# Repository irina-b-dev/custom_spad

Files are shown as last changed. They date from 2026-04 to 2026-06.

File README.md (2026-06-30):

# Custom Single Photon Avalanche Detection system with integrated coincidence logic

## Overview
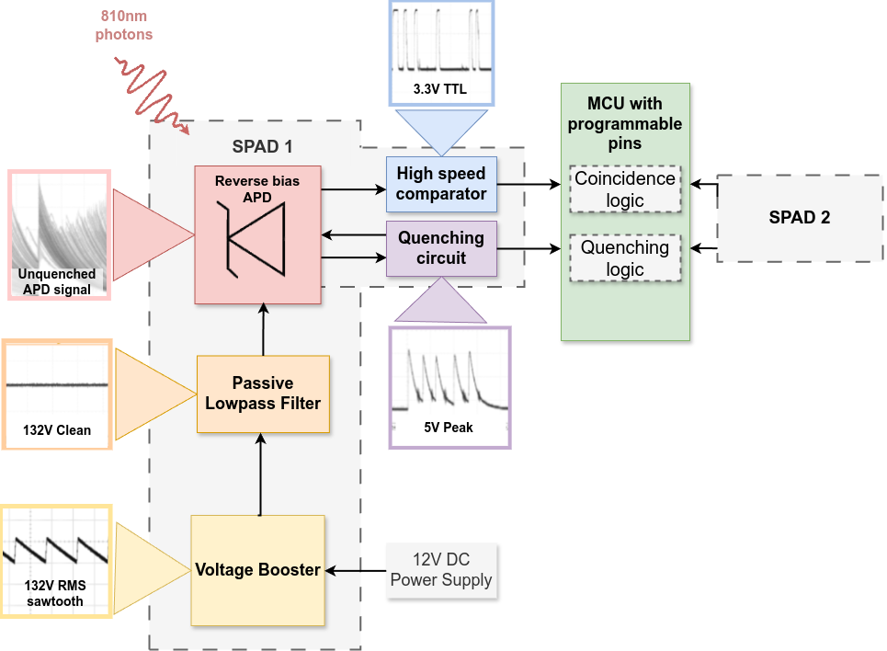
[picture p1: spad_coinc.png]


## BOM

Minimal working

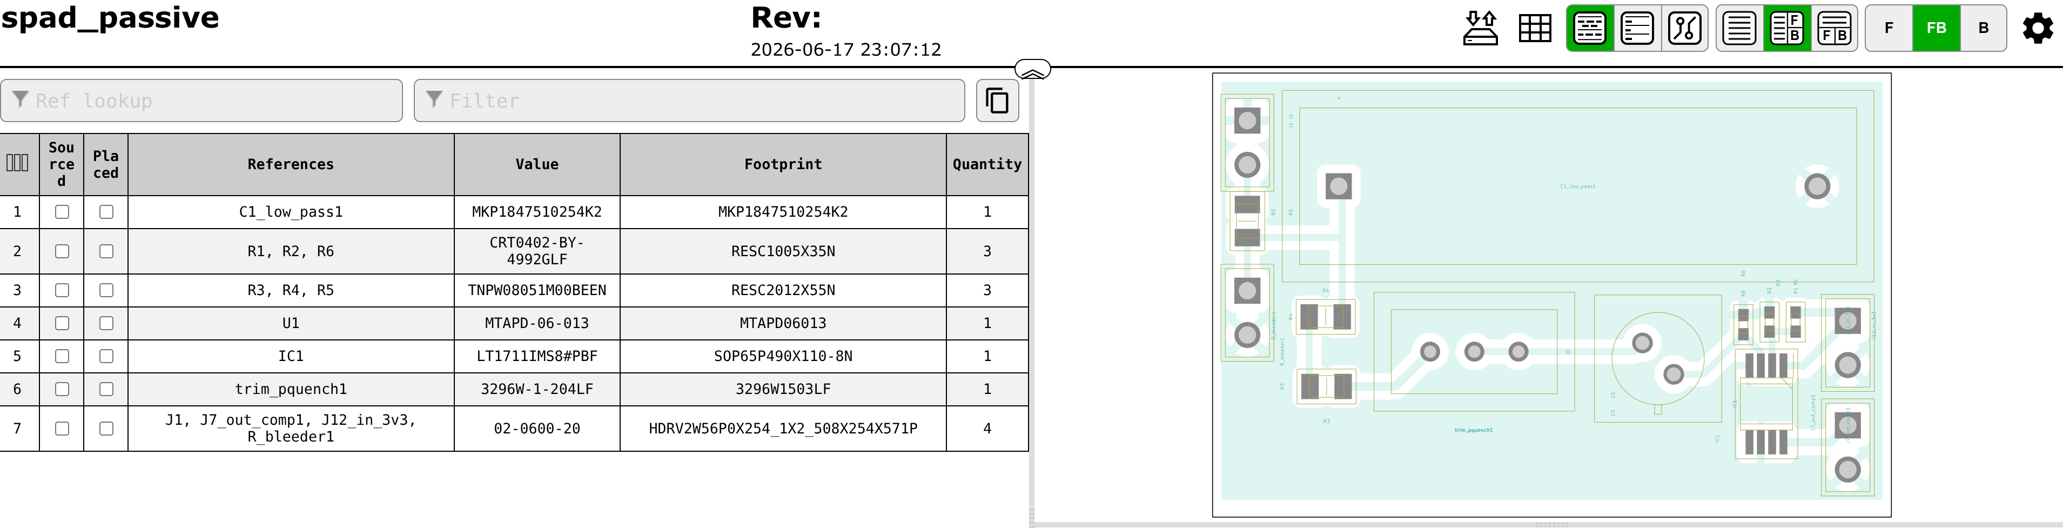
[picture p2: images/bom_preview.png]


[bom_interactive](./bom/ibom.html)

## BOM in test

### APD
| Name | Link | Price | Qty | Description | Code | Check |
| ---- | --- | --- | --- | --- | --- | ----- |
| APD  | https://ro.mouser.com/ProductDetail/193-MTAPD-06-001 | 37,21 € | 2 | Peak Wavelength: 800nm | 193-MTAPD-06-001 | [x] |

### Voltage Booster + Filter

| | | | | | | | | |
| --- | --- | --- | --- | ----- | --- | ---- | --- | --- |
| ---  --- |
| Ref. | Mfg. | Part No.  | Description |
| R | -- | -- | resistor | 100K  | | | | |
| C3 | -- | -- | capacitor | 1µF | | | | |
|YH11068A | | | | booster | |

### Quenching + Comparator

| | | | | | | | | |
| --- | --- | --- | --- | ----- | --- | ---- | --- | --- |
| ---  --- | | For SPAD  | | | | | | |
| | | | | | | | | |
| Ref. | Mfg. | Part No.  | Description | | | | | |
| APD | -- | DAPD | diode | | | | | |
| C1 | -- | -- | capacitor | 33µF  | 2.7V | | | |
| C2 | -- | -- | capacitor | 1µF | | | | |
| C3 | -- | -- | capacitor | 1µF | | | | |
| C4 | -- | -- | capacitor | 1µF | | | | |
| C5 | -- | -- | capacitor | 100nF | | | | |
| C6 | -- | -- | capacitor | 10nF  | | | | |
| C7 | -- | -- | capacitor | 100nF | | | | |
| C8 | -- | -- | capacitor | 100nF | | | | |
| Cj | -- | -- | capacitor | 1pF | 1KV | | | |
| Cn | -- | -- | capacitor | 10nF  | | | | |
| D1 | OnSemi | 1N5818 | diode | | | | | |
| D2 | OnSemi | 1N5819 | diode | | | | | |
| D3 | Vishay | BAT54 | diode | | | | | |
| D4 | Rohm | BAS21HY | diode | | | | | |
| D5 | Rohm | BAS21HY | diode | | | | | |
| L1 | -- | -- | inductor | 33µH  | 1.35A pk | | | |
| M1 | International Rectifier | IRF7832 | MOSFET | | | | | |
| M2 | Siliconix | Si7336ADP | MOSFET | | | | | |
| maboi | -- | -- | resistor | 1M | | | | |
| R1 | -- | -- | resistor | 1M | 1.00% | 0.1W | | |
| R2 | -- | -- | resistor | 100K  | | | | |
| R3 | -- | -- | resistor | 49.9K | | | | |
| R4 | -- | -- | resistor | 6.8K  | | | | |
| R5 | -- | -- | resistor | 20K | | | | |
| R6 | -- | -- | resistor | 300 | | | | |
| R7 | -- | -- | resistor | 1K | | | | |
| R8 | -- | -- | resistor | 1.9K  | | | | |
| R9 | -- | -- | resistor | 6K | | | | |
| R10 | -- | -- | resistor | 500K  | | | | |
| R11 | -- | -- | resistor | 1K | | | | |
| R13 | -- | -- | resistor | 150K  | | | | |
| Rbias | -- | -- | resistor | 14K | | | | |
| Rbias1 | -- | -- | resistor | 10K | | | | |
| Rdivider | -- | -- | resistor | 140K  | | | | |
| Rdrain | -- | -- | resistor | 90K | | | | |
| Re0 | -- | -- | resistor | 10 | | | | |
| Ri | -- | -- | resistor | 200K  | | | | |
| Rth | -- | -- | resistor | 1M | | | | |
| U1 | Analog Devices | LT1172 | integrated circuit | | | | | |
| U2 | Analog Devices | LT1711 | integrated circuit | | | | | |
| U3 | Analog Devices | AD8605 | integrated circuit | | | | | |
| | | | | | | | | |
| RP_Pico | | Rasberry Pi Pico |  MCU | | | | | |
| | | | | | | | | |

## PIO snippet for detection

```asm

.program detect_pulse

; Assumes:
; - Pin 2 - 4,5 = pulse input
; - Pin  0 - 2,3 = gate/control pin
; - pin base in C must include both

start:
    wait 1 pin 2           ; Wait for rising edge on pulse input
    ;wait 1 pin 0
    jmp pin do_push                       ;jmp pin do_push     ; 
    jmp do_push     ;jmp start              ; Otherwise, skip

do_push:
    in x, 32               ; 
    push block
    jmp start
```

### Note
This project is part of a [bigger project](https://github.com/irina-b-dev/custom-qkd-source)

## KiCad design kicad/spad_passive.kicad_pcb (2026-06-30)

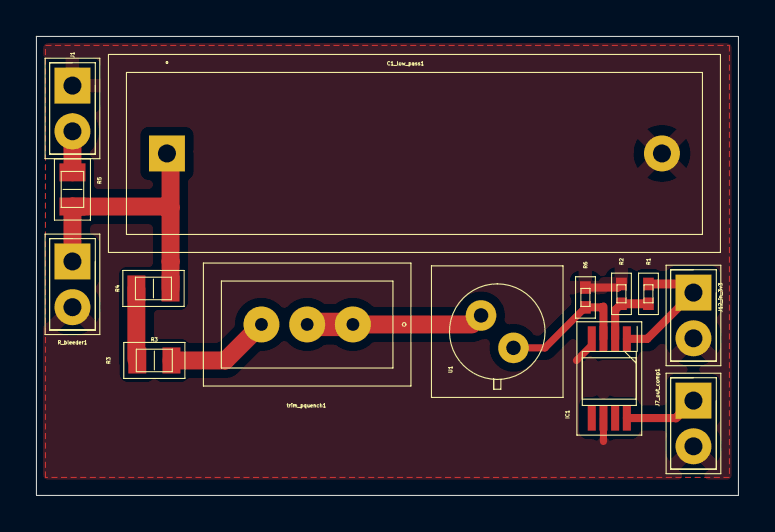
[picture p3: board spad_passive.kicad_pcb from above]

Board: 2 copper layers, 39.0 x 25.5 mm, 14 parts (0 on the bottom side), 10 nets.

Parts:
C1_low_pass1: MKP1847510254K2
IC1: LT1711IMS8#PBF; SOP65P490X110-8N
J1, J7_out_comp1, J12_in_3v3: 02-0600-20; HDRV2W56P0X254_1X2_508X254X571P
R1, R2, R6: CRT0402-BY-4992GLF; RESC1005X35N
R3, R4, R5: TNPW08051M00BEEN; RESC2012X55N
R_bleeder1: 02-0600-20; HDRV2W56P0X254_1X2_508X254X571P
U1: MTAPD-06-013; MTAPD06013
trim_pquench1: 3296W-1-204LF; 3296W1503LF

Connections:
+3.3V: IC1.1 (V+), J12_in_3v3.1, R1.2
+132V: J1.2, R5.1
GND: C1_low_pass1.2, IC1.4 (V-), IC1.6 (GND), J1.1, J7_out_comp1.2, J12_in_3v3.2, R2.2, R6.2, R_bleeder1.2
unnamed: C1_low_pass1.1, R4.1, R5.2, R_bleeder1.1
unnamed: IC1.2 (+IN), R1.1, R2.1
unnamed: IC1.3 (-IN), R6.1, U1.2 (APD+)
unnamed: IC1.8 (~Q), J7_out_comp1.1
unnamed: R3.1, R4.2
unnamed: R3.2, trim_pquench1.3
unnamed: U1.1 (APD-), trim_pquench1.1, trim_pquench1.2

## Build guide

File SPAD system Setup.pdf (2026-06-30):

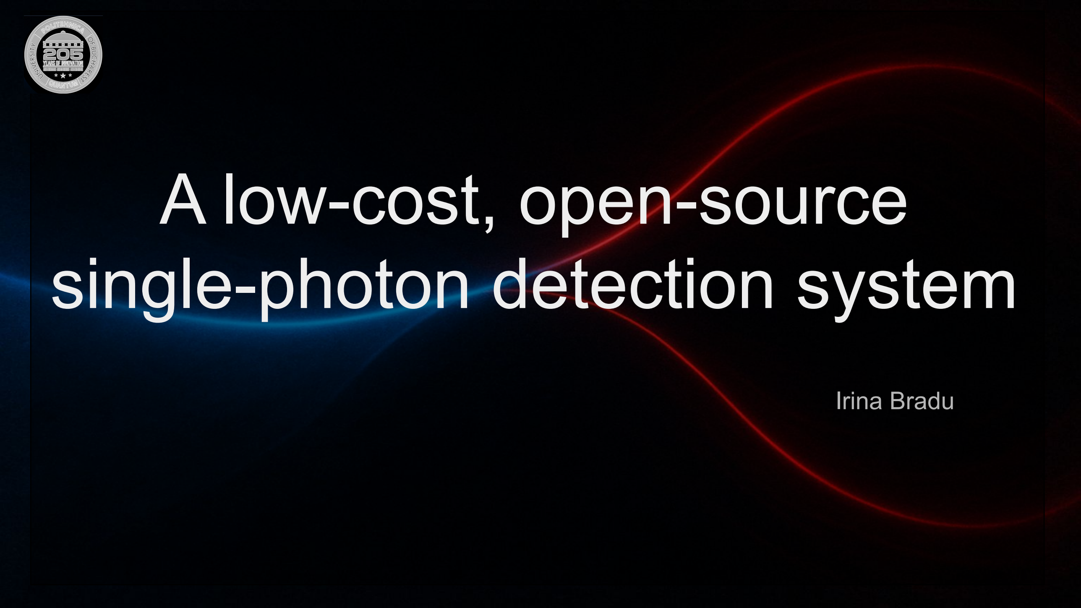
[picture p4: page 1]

# A low-cost, open-source single-photon detection system

Irina Bradu

Motivation

- Educational outreach
- Hardware experimentation
- Cost constraints

This was made at home.

This project was fully self founded.

Open-source, so you can try it yourself.

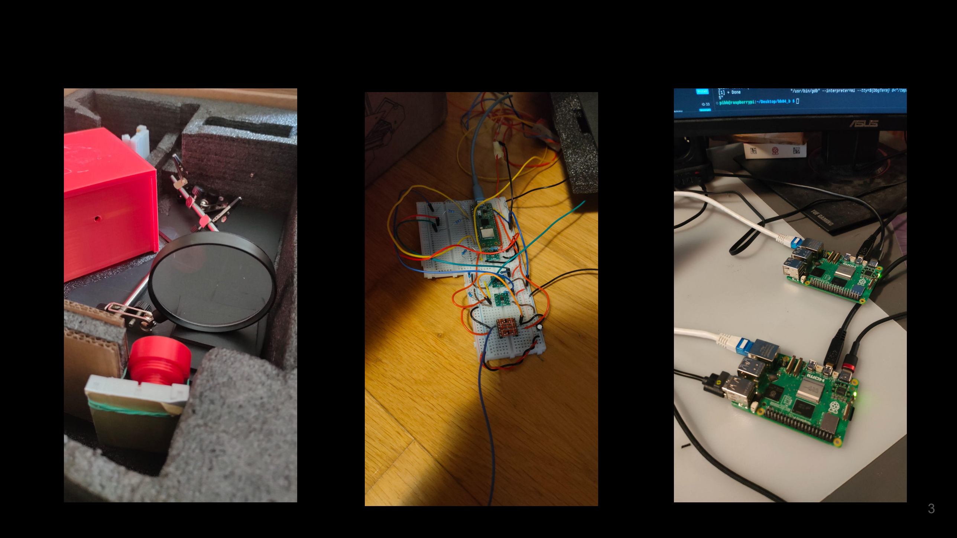
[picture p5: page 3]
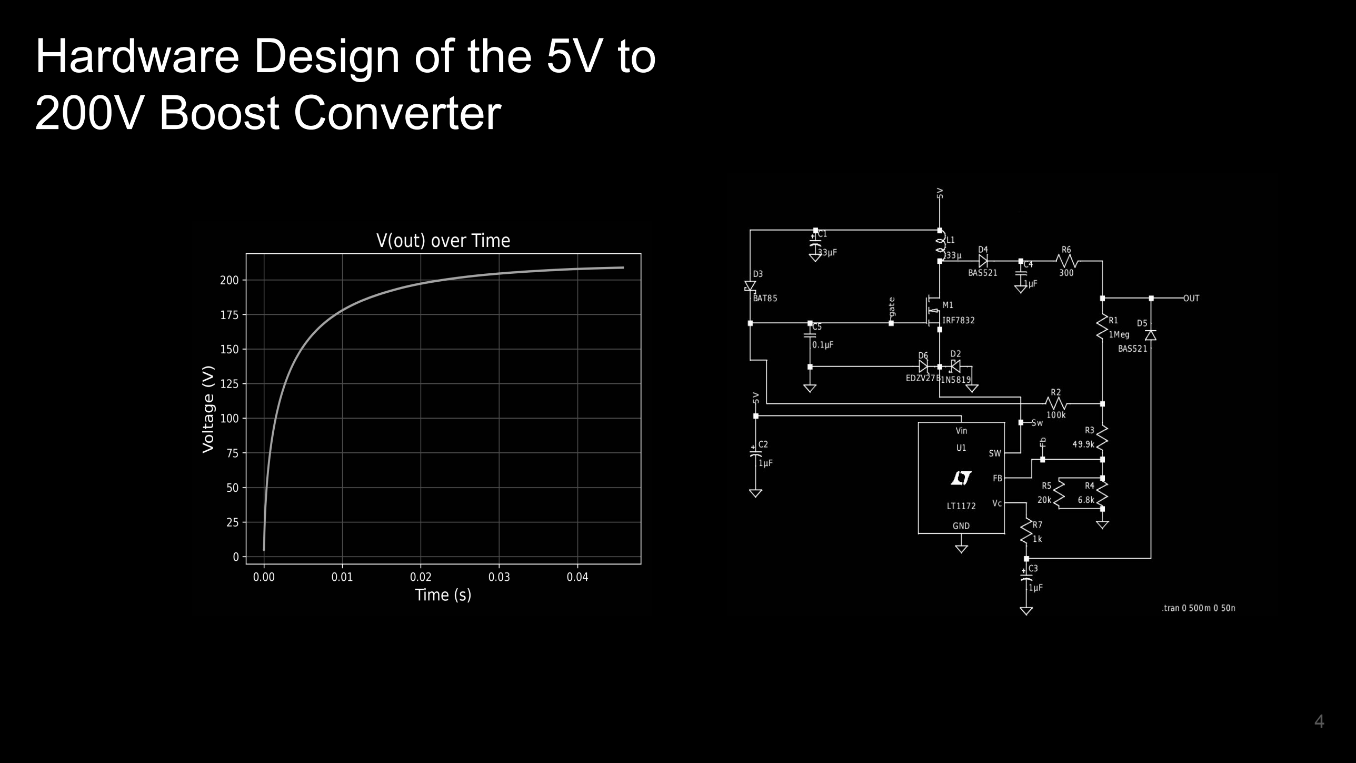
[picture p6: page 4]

Hardware Design of the 5V to 200V Boost Converter

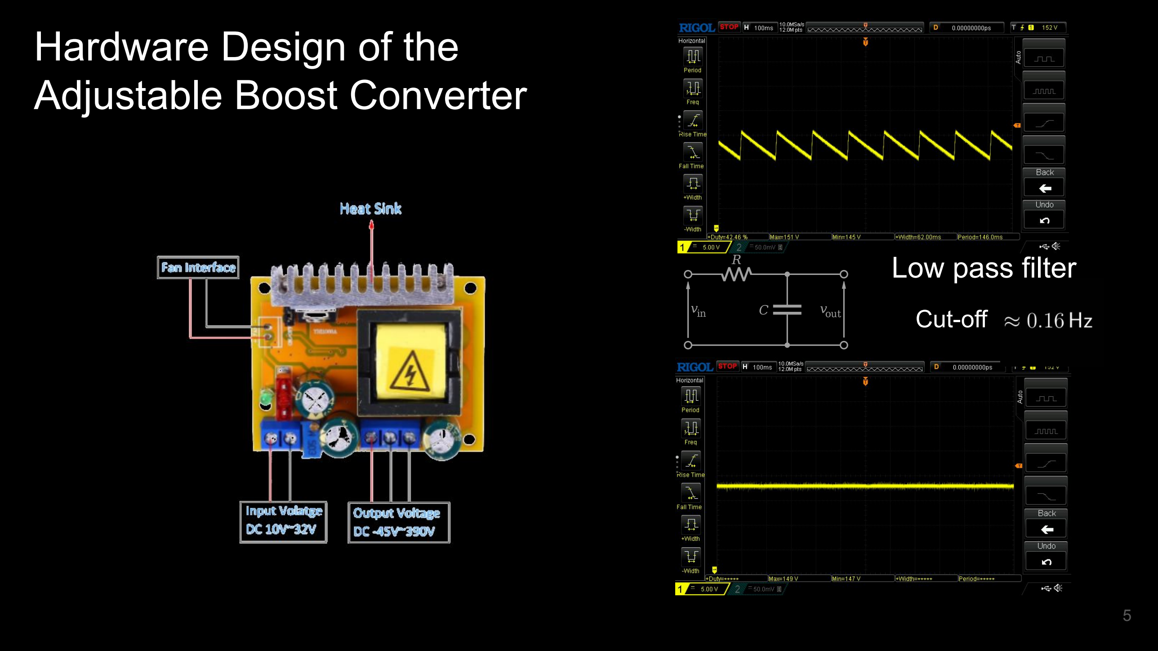
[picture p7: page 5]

Hardware Design of the
Adjustable Boost Converter

Cut-off

Low pass filter

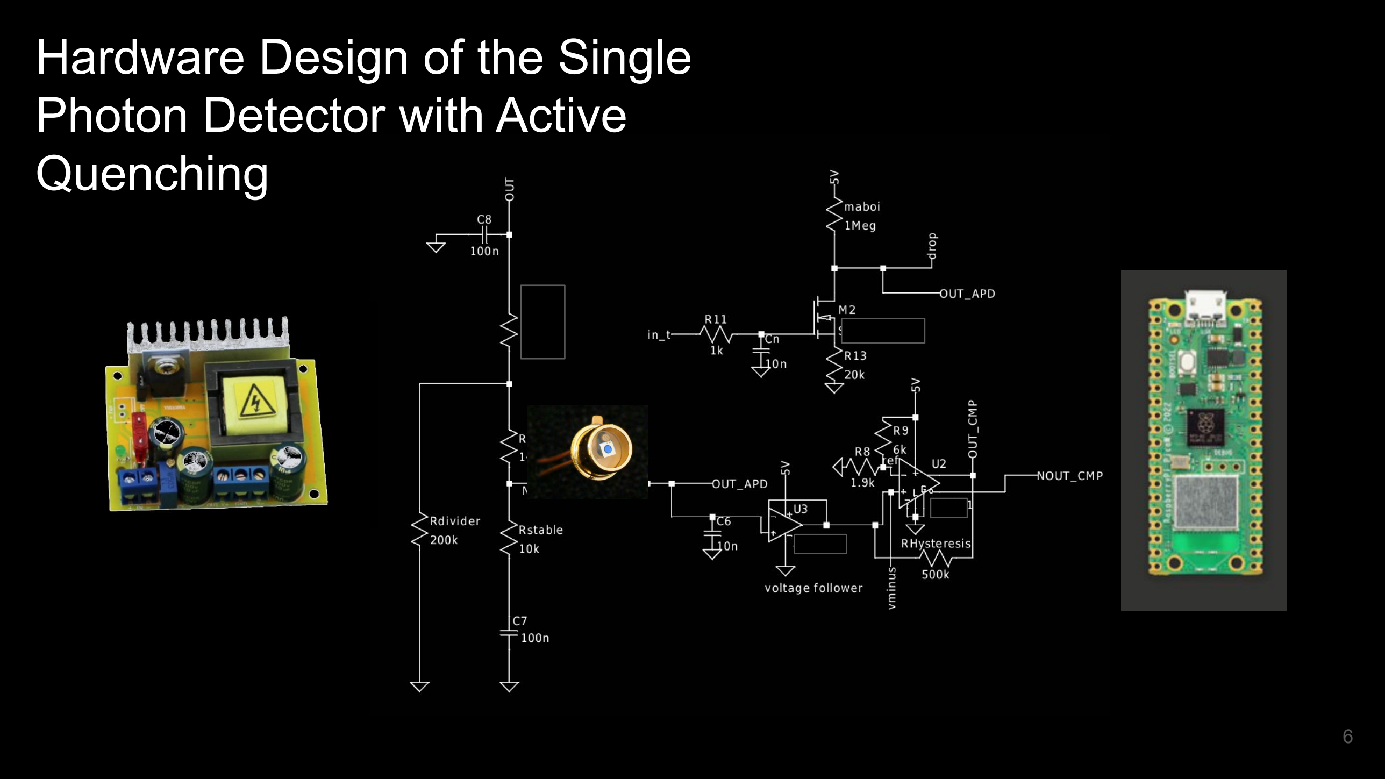
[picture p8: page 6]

Hardware Design of the Single Photon Detector with Active Quenching

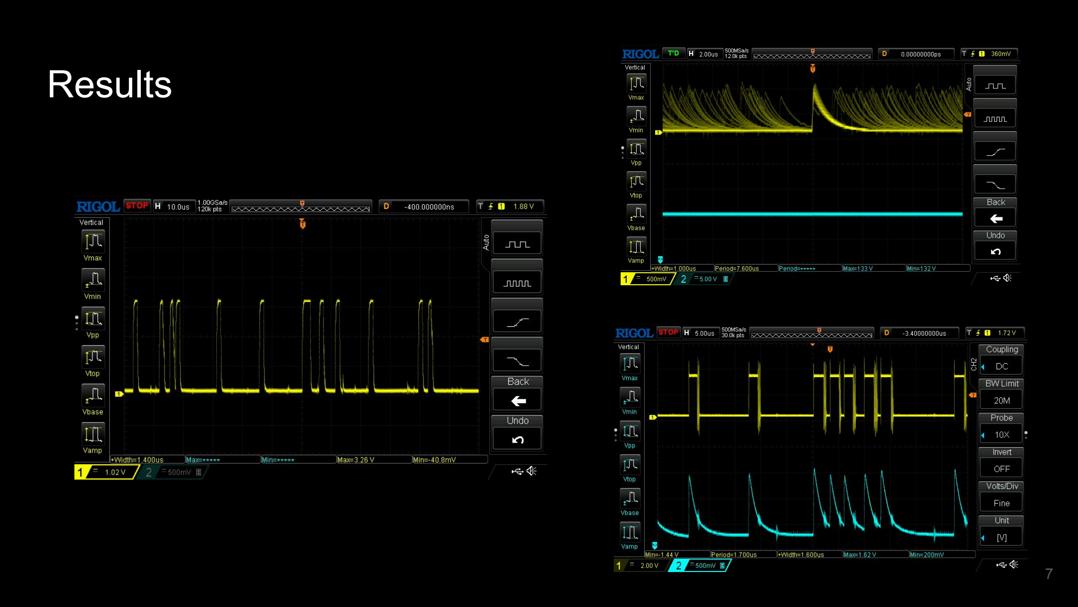
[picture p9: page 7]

Results

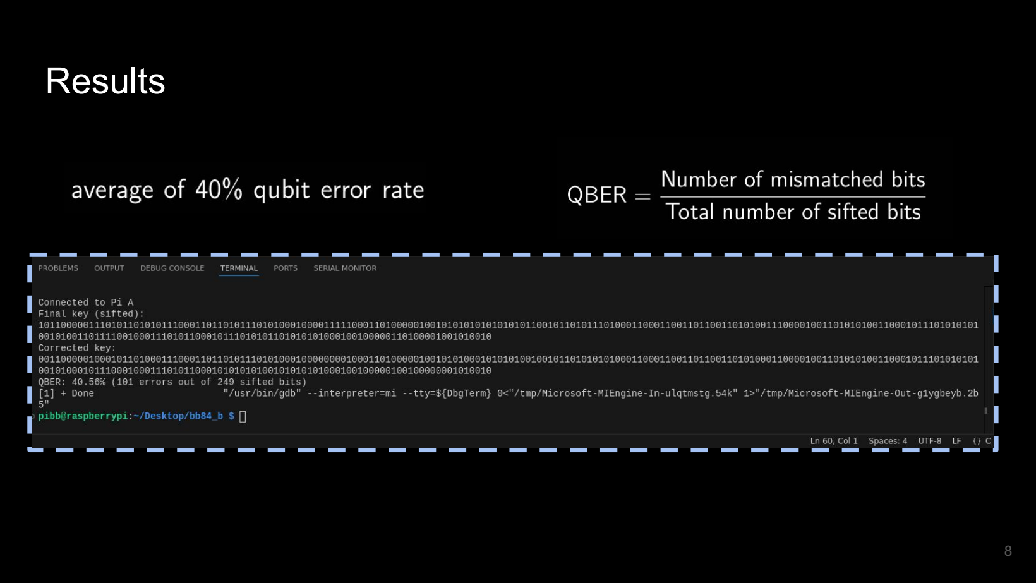
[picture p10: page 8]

Results
